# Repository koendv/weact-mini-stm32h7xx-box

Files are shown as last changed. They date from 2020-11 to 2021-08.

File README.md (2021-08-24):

# Box for WeAct MiniSTM32H7xx
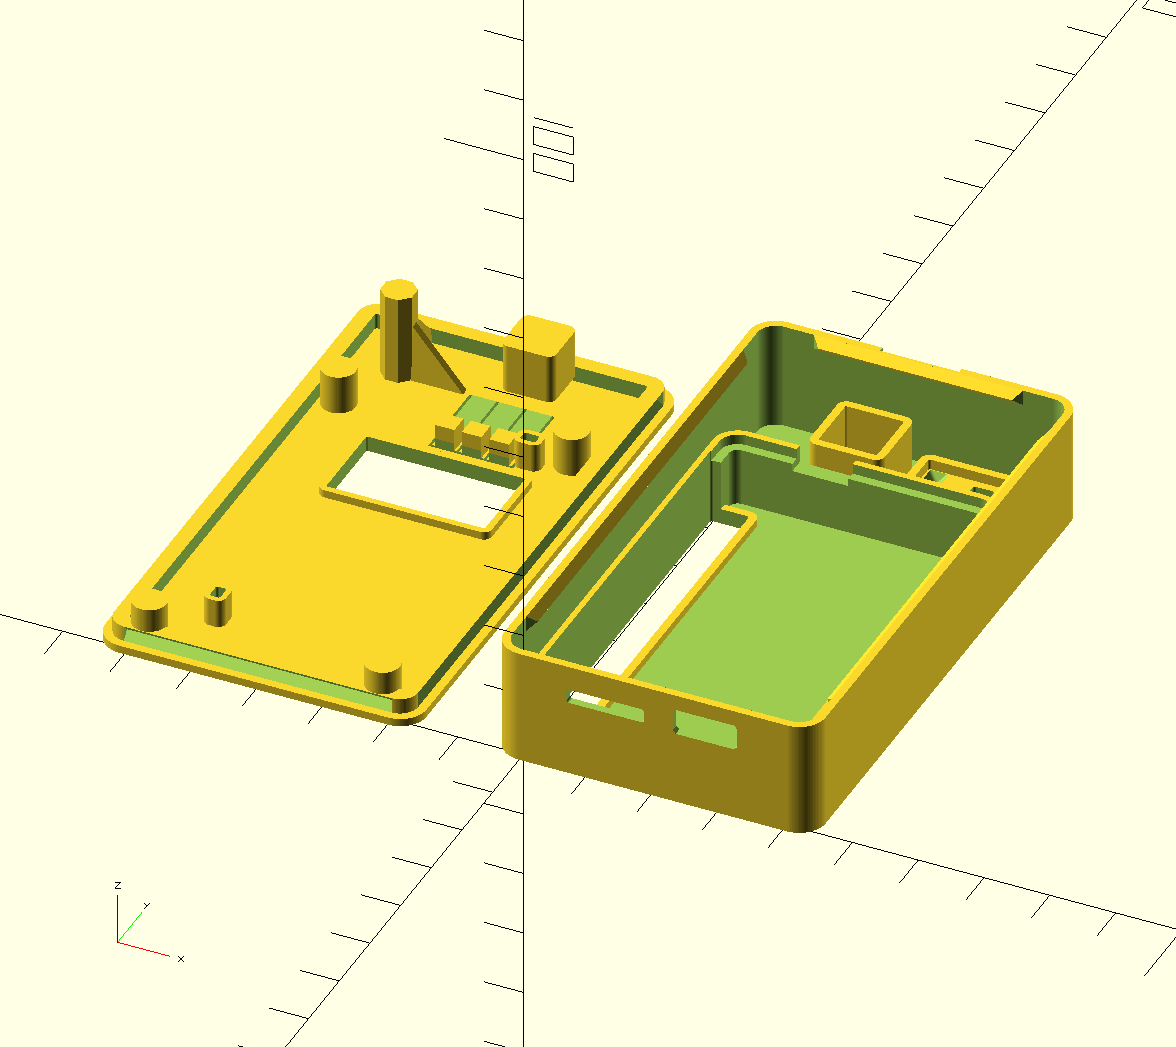
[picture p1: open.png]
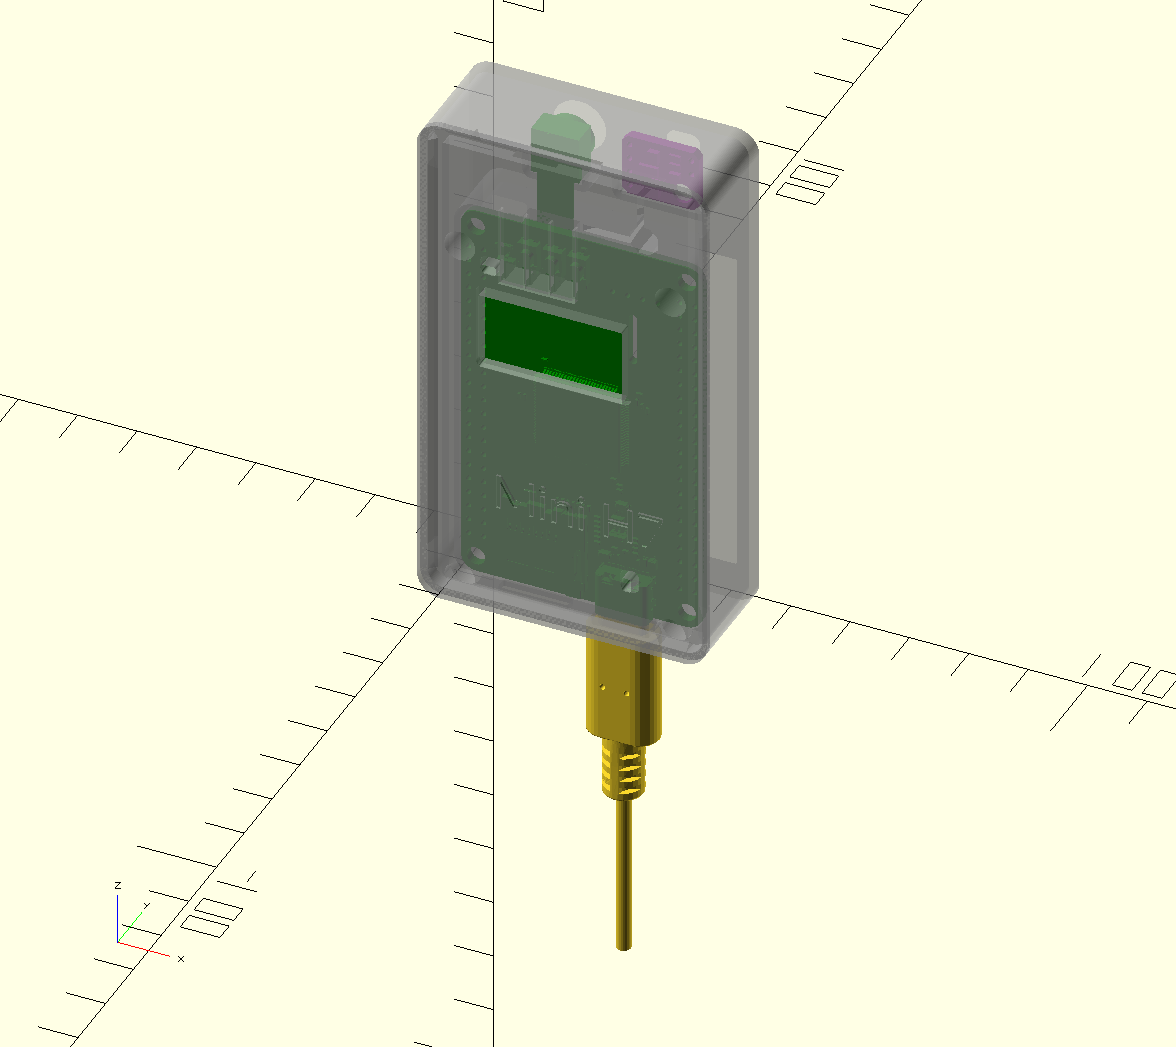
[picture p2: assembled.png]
|  |  |
|--|--|
| open | assembled|

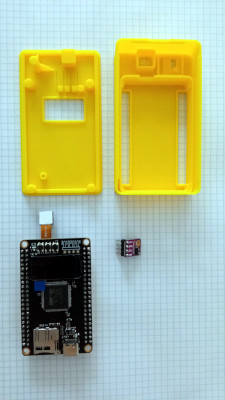
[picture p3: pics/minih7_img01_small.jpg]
before
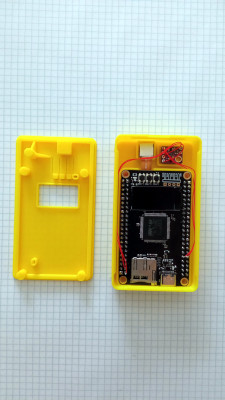
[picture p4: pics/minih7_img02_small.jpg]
after
| | |
|--|--|
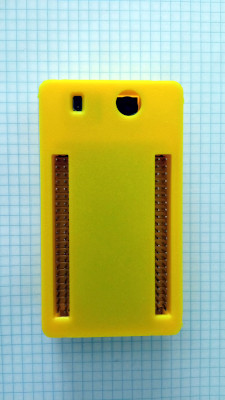
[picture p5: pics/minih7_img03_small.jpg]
back
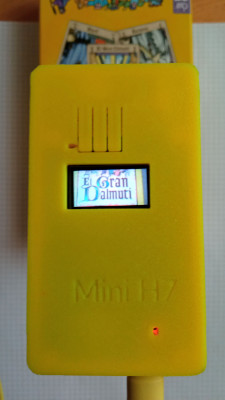
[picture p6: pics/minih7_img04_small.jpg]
front
| | |

This is a box for the [WeAct-TC MiniSTM32H7xx](https://github.com/WeActTC/MiniSTM32H7xx) board. The MiniSTM32H7xx runs micropython and openmv (Open Machine Vision). The board includes a camera and lcd screen.

Additionally, there is room to mount a [GY-530](GY-530.jpg) board, a VL53L0X time-of-flight laser range finder. This distance sensor can be used to check whether there is something in front of the lens. 

Connections for the optional VL53L0X laser range finder:

|VL53L0X|MiniSTM32H7xx|
|---|---|
|Vin|3V3|
|GND|GND|
|SCL|D12|
|SDA|D13|

## Download

[STL files](https://github.com/koendv/weact-mini-stm32h7xx-box/releases) for 3D printer. The box consists of two parts, a top and a bottom.

## Hardware

Notes about the WeAct-TC MiniSTM32H7xx camera hardware I'm using with OpenMV.

- [camera](https://www.aliexpress.com/item/1005001475058305.html) with lcd screen. Runs micropython.
- Installation [manual](https://github.com/WeActTC/MiniSTM32H7xx)
- How to [install the lcd](https://m.bilibili.com/video/av286164536)
- camera [firmware](https://gitee.com/WeAct-TC/MiniSTM32H7xx/tree/master/SDK/openmv/Firmwares/)
- [tool](https://gitee.com/WeAct-TC/MiniSTM32H7xx/tree/master/Soft) to upload firmware to the camera
- [openmv ide](https://github.com/koendv/openmv-ide-raspberrypi) for raspberry pi
- [VL53L0X](https://github.com/ramithuh/OpenMV-VL53L0X) laser distance sensor to check whether there is something in front of the camera

## OpenSCAD notes

This 3D model was made as follows:

- Download [3D model of MiniSTM32H7xx](https://github.com/WeActTC/MiniSTM32H7xx) pcb from WeAct git.
- Convert 3D model to stl with FreeCAD
- Extract 3D models of buttons, leds, connectors, pcb to stl with FreeCAD
- Download [3D model of GY-530](https://www.thingiverse.com/thing:2558558) from Thingiverse
- Import 3D models in OpenSCAD
- Use 3D models of leds, buttons and connectors as guides for holes in enclosure

*not truncated*

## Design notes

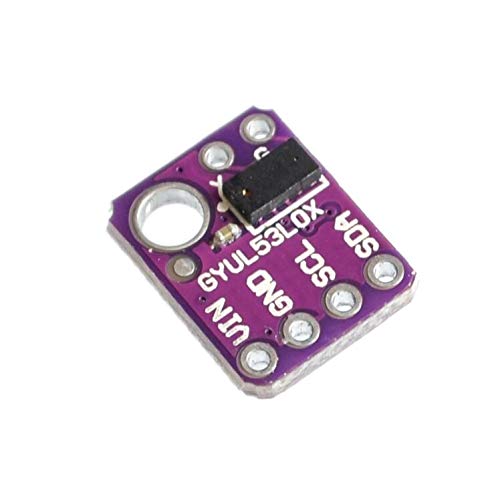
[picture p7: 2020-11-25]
GY-530.jpg

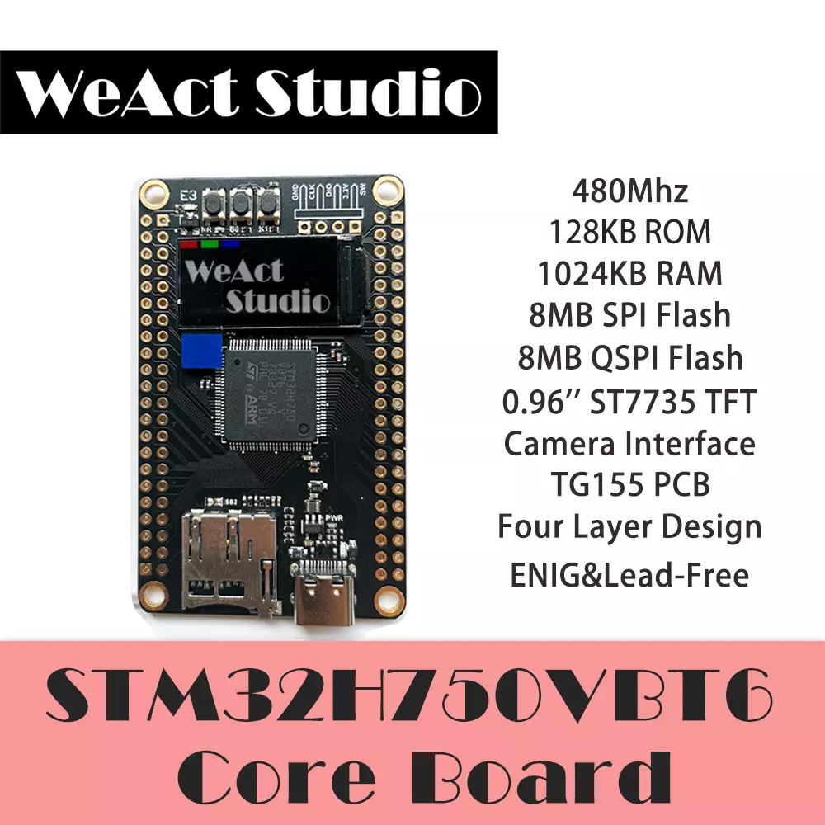
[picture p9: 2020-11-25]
MiniSTM32H7xx.jpg

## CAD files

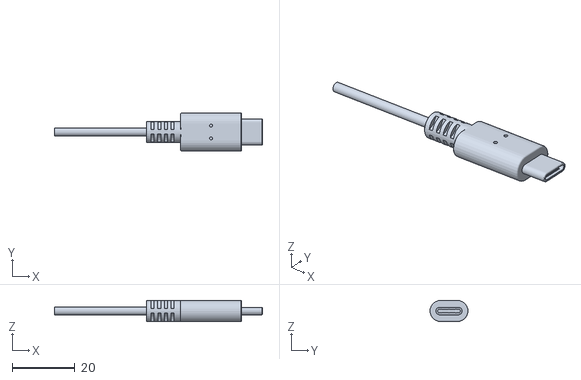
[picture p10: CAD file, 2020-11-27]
usb-c.stl
66.2 x 12.1 x 6.70

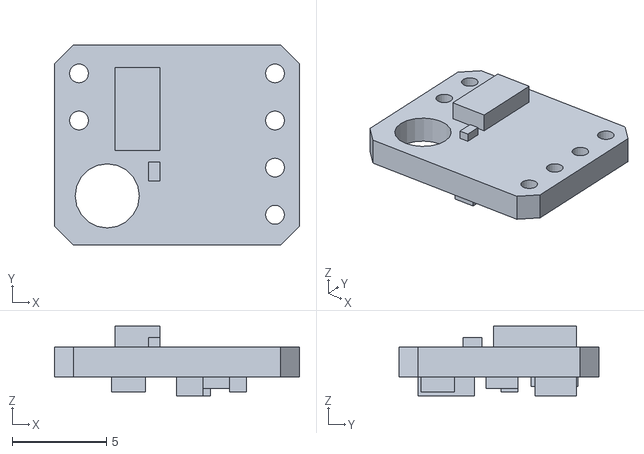
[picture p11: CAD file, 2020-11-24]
GY-530.stl
13.0 x 10.6 x 3.70

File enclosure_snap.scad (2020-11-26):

// Customizable snap-fit electronics project box enclosure
// https://www.thingiverse.com/thing:2866563/files


// Which one would you like to see?
part = "both"; // [box:Box only, top: Top cover only, both: Box and top cover]

// Size of your printer's nozzle in mm
nozzle_size = 0.4;

// Number of walls the print should have
number_of_walls = 3; // [1:5]

// Tolerance (use 0.2 for FDM)
tolerance = 0.2; // [0.1:0.1:0.4]

// Outer x dimension in mm
x=w1+2*number_of_walls*nozzle_size+nozzle_size;

// Outer y dimension in mm
y=h1+2*number_of_walls*nozzle_size+nozzle_size;

// Outer z dimension in mm
z=z1+2*number_of_walls*nozzle_size;

echo("Box:",x,y,z);

// Radius for rounded corners in mm
radius=4; // [1:20]

/* Hidden */
$fn=100;

wall_thickness=nozzle_size*number_of_walls;
hook_thickness = 3*nozzle_size;

top_cover_wall_thickness = hook_thickness + wall_thickness;

module bottom_box () {
    difference(){
        // Solid box
        linear_extrude(z-wall_thickness+eps1){
            minkowski(){
                square([x-radius*2,y-radius*2], center=true);
                circle(radius);
            }
        }
        
        // Hollow out
        translate([0,0,wall_thickness]) linear_extrude(z){
            minkowski(){
                square([x-radius*2-wall_thickness*2+wall_thickness*2,y-radius*2-wall_thickness*2+wall_thickness*2], center=true);
                circle(radius-wall_thickness);
            }
        }
    }
    left_hook(); // left hook
    rotate([180,180,0]) left_hook(); // right hook
    front_hook(); // front hook
    rotate([180,180,0]) front_hook(); // back hook
    // TODO: hooks on the other two sides
}

module left_hook () {
    
    translate([(x-2*wall_thickness)/2,-y/2+radius*2,z-wall_thickness]) rotate([0,90,90]) {
        difference(){
            linear_extrude(y-2*radius*2){
    polygon(points=[[0,0],[2*hook_thickness,0],[hook_thickness,hook_thickness]]);
        }
             translate([hook_thickness, hook_thickness, 0]) rotate([45,0,0]) cube(2*hook_thickness, center=true);
             translate([hook_thickness, hook_thickness, y-2*radius*2]) rotate([45,0,0]) cube(2*hook_thickness, center=true);        
        }
    }
}
    

module front_hook () {
    translate([(-x+4*radius)/2,-y/2+wall_thickness,z-wall_thickness]) rotate([90,90,90]) {
        difference(){
        linear_extrude(x-2*radius*2){
    polygon(points=[[0,0],[2*hook_thickness,0],[hook_thickness,hook_thickness]]);
    }
             translate([hook_thickness, hook_thickness, 0]) rotate([45,0,0]) cube(2*hook_thickness, center=true);
             translate([hook_thickness, hook_thickness, x-2*radius*2]) rotate([45,0,0]) cube(2*hook_thickness, center=true);
        }
    }
}


module right_groove () {
    translate([-tolerance/2+(x-2*wall_thickness)/2,-y/2+radius,wall_thickness+hook_thickness*2]) rotate([0,90,90]) linear_extrude(y-2*radius){
    polygon(points=[[0,0],[2*hook_thickness,0],[hook_thickness,hook_thickness]]);
    }
}


module front_groove () {
    translate([(-x+2*radius)/2,-y/2+wall_thickness+tolerance/2,wall_thickness+hook_thickness*2]) rotate([90,90,90]) linear_extrude(x-2*radius){
    polygon(points=[[0,0],[2*hook_thickness,0],[hook_thickness,hook_thickness]]);
    }
}

module top_cover () {

    // Top face
    linear_extrude(wall_thickness){
        minkowski(){
            square([x-radius*2,y-radius*2], center=true);
            circle(radius);
        }
    }
    
    difference(){
        // Wall of top cover
        linear_extrude(wall_thickness+hook_thickness*2){
            minkowski(){
                square([x-radius*2-wall_thickness*2-tolerance+wall_thickness*2,y-radius*2-wall_thickness*2-tolerance+wall_thickness*2], center=true);
                circle(radius-wall_thickness);
            }
        }
        
        // Hollow out
        // TODO: If radius is very small, still hollow out

        translate([0,0,wall_thickness]) linear_extrude(z){
            minkowski(){
                square([x-radius*2-wall_thickness*2-2*top_cover_wall_thickness-tolerance+wall_thickness*2+top_cover_wall_thickness*2,y-radius*2-wall_thickness*2-2*top_cover_wall_thickness-tolerance+wall_thickness*2+top_cover_wall_thickness*2], center=true);
            circle(radius-wall_thickness-top_cover_wall_thickness);
            }
        }
    right_groove();
    rotate([180,180,0]) right_groove();
    front_groove();
    rotate([180,180,0])  front_groove();
    }
  

}

// left_hook();
// print_part();

module print_part() {
	if (part == "box") {
		bottom_box();
	} else if (part == "top") {
		top_cover();
	} else if (part == "both") {
		both();
	} else {
		both();
	}
}

module both() {
	translate([0,-(y/2+wall_thickness),0]) bottom_box();
    translate([0,+(y/2+wall_thickness),0]) top_cover();
}

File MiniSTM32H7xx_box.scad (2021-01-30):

/*
 * Box for WeAct-TC Mini-STM32H7xx openmv board
 * and gy-530 vl53l0x laser ranging sensor.
 */

connector = true; // hole for dupont connectors
laser_distance_sensor = true; // hole for gy-530 vl53l0x laser ranging sensor

eps1=0.001;
eps2=2*eps1;
infinity=100;
inch=25.4;

top_z=6.0;    // top components
bottom_z=9.0; // bottom components
pcb_z=1.6;    // pcb

w1=46.0;
h1=85.0;
w2=40.64;
h2=66.88;
z1=top_z+pcb_z+bottom_z;
d1=5.2;
r1=d1/2; // distance screw center to pcb edge

/* camera */
cam_x=14.5;
cam_y=79.0;
cam_d=8.5;
cam_z_offset=1.2; // distance between camera flex cable and pcb

/* buttons */
button_y = 62.0;
button_x1 = 11.9;
button_x2 = 16.1;
button_x3 = 20.2;
button_w = 3.0;
button_h = 3.0;
button_z = top_z-1.3;
button_l = 13.6;

led_z = top_z - 1.6;

distance_sensor_x = 32.0;
distance_sensor_y = 79.0;
distance_sensor_z = 1.2-eps1;

usb_x = 28.22;
usb_y = 4.8;

clearance_fit=0.4;

include <enclosure_snap.scad>

/* through hole */
module hole(){
    translate([0,0,-infinity/2])
    linear_extrude(infinity)
    offset(nozzle_size/2)
    projection()
    children();
}

/* pcb screw centers */
module screw_positions() {
    translate([r1, r1, 0])
    children();
    translate([r1, h2-r1, 0])
    children();
    translate([w2-r1, h2-r1, 0])
    children();
    translate([w2-r1, r1, 0])
    children();
}

/* engraving */
module small_text(txt) {
    text_h=nozzle_size; // one layer
    translate([0,0,-text_h+eps1])
    linear_extrude(2*text_h) text(txt, size = 6, halign = "center", valign = "center",font="Lato:style=Regular");
}

// --------------------------------------------------------------------------------
// Imports from cad

module led1_hole() {
    translate([0,0,-infinity/2])
    linear_extrude(infinity)
    translate([31.2, 10.3])
    offset(nozzle_size)
    square([0.8,1.6], center=true);
}

module led2_hole() {
    translate([0,0,-infinity/2])
    linear_extrude(infinity)
    translate([8.0, 62.1])
    offset(nozzle_size)
    translate([-0.8,-0.4,0])
    square([1.6,0.8]); // gives thin wall
}

module led1_body() {
    translate([0,0,-wall_thickness-led_z])
    linear_extrude(led_z)
    offset(3*nozzle_size)
    translate([31.2, 10.3])
    square([0.8,1.6], center=true);
}

module led2_body() {
    translate([0,0,-wall_thickness-led_z])
    linear_extrude(led_z)
    offset(3*nozzle_size)
    translate([8.0, 62.1])
    square([1.6,0.8], center=true);
}

module distance_sensor() {
    // 3d model of gy-530 module, center of vl53l0x at [0,0,0]
    translate([-3.2,64.6,-3.7])
    import("GY-530.stl");
}

module distance_sensor_hole() {
    translate([distance_sensor_x,distance_sensor_y,distance_sensor_z])
    rotate([0,0,180])
    {
        // vl53l0x sensor
        translate([0,0,-wall_thickness/2])
        linear_extrude(wall_thickness*2)
        offset(nozzle_size)
        square([2.4,4.4],center=true);

        // cone cutout
        translate([0,0,-wall_thickness])
        hull() {
            translate([0,0,wall_thickness])
            linear_extrude(eps1)
            offset(nozzle_size)
            square([2.4,4.4],center=true);
            translate([0,0,-eps2])
            linear_extrude(eps2)
            offset(nozzle_size+wall_thickness)
            square([2.4,4.4],center=true);
            }

        // small cap
        translate([0.9,3.3,0.2])
        linear_extrude(0.9+eps1)
        offset(nozzle_size)
        square([0.6,1.0],center=true);

        // pins
        translate([7.3,1.8,1.1+eps1])
        hull() {
            linear_extrude(eps1)
            offset(nozzle_size)
            square([2.0,0.4*inch],center=true);
            translate([0,0,-1.2])
            linear_extrude(eps1)
            offset(nozzle_size)
            square([eps1,0.35*inch],center=true);
        }
    }
}

module distance_sensor_body() {
    translate([distance_sensor_x,distance_sensor_y,distance_sensor_z])
    rotate([0,0,180])
    {
        translate([-1.6,4.6,1.1])
        rotate([0,0,180/8])
        cylinder(d=3.2, h=1.2, $fn=8);

        translate([2.1,1.9,1.1]) {
            translate([0,0,-1.1])
            linear_extrude(1.1+eps1)
            offset(wall_thickness + nozzle_size)
            square([13.0,10.6], center = true);
            linear_extrude(1.6+eps1)
            difference() {
                offset(wall_thickness + nozzle_size)
                square([13.0,10.6], center = true);
                offset(nozzle_size)
                square([13.0,10.6], center = true);
            }
        }
    }
}

module distance_sensor_support() {
    support_h=wall_thickness+top_z+pcb_z+bottom_z+pcb_z+wall_thickness-distance_sensor_z-4.3;
    translate([distance_sensor_x,distance_sensor_y,0])
    rotate([0,0,180])
    translate([-1.6,4.6,0])
    mirror([0,0,1]) {
        rotate([0,0,180/8])
        cylinder(d=5.2,h=support_h,$fn=8);
        buttress_h=support_h*3/4;
        hull() {
            translate([0,-wall_thickness/2,buttress_h])
            cube([wall_thickness,wall_thickness,eps1]);
            cube([buttress_h,wall_thickness,eps1]);
        }
        rotate([0,0,-90])
        hull() {
            translate([0,-wall_thickness/2,buttress_h])
            cube([wall_thickness,wall_thickness,eps1]);
            cube([buttress_h,wall_thickness,eps1]);
        }
    }
}

module lcd_hole() {
    hole()
    translate([6.5,44,0])
    cube([23.7,12.8,eps1]);
}

module lcd_body() {
    translate([6.5,44,0])
    mirror([0,0,1])
    linear_extrude(2*wall_thickness)
    offset(wall_thickness)
    square([23.7,12.8]);
}

module button_body() {
    translate([0,0,-button_z/2]) {
        translate([button_x3, button_y,0])
        cube([button_w, button_h, button_z], center=true);

        translate([button_x2, button_y,0])
        cube([button_w, button_h, button_z], center=true);

        translate([button_x1, button_y,0])
        cube([button_w, button_h, button_z], center=true);
    }
}

module button_holes() {
    d = (button_x2 - button_x1)/2;
    x1 = button_x1 - d; // first
    x2 = button_x1 + d;
    x3 = button_x2 + d;
    x4 = button_x3 + d; // last
    y0 = button_y-button_h/2+button_l/2-clearance_fit;
    z0 = 4*wall_thickness+eps1;

    translate([x1, y0, 0])
    cube([clearance_fit, button_l, z0], center=true);

    translate([x2, y0, 0])
    cube([clearance_fit, button_l, z0], center=true);

    translate([x3, y0, 0])
    cube([clearance_fit, button_l, z0], center=true);

    translate([x4, y0, 0])
    cube([clearance_fit, button_l, z0], center=true);

    translate([(x1+x4)/2, button_y-button_h/2-clearance_fit/2, 0])
    cube([x4-x1+clearance_fit, clearance_fit, z0], center=true);

    translate([x1-clearance_fit/2, button_y+button_h/2, -2*wall_thickness])
    cube([x4-x1+clearance_fit, button_l-button_h-clearance_fit, wall_thickness]);
}

module usb() {

    usb_c_x2 = 9.0;
    usb_c_y2 = 3.2;
    usb_c_z2 = 9.5;
    
    if (1)
    translate([usb_x,0,0])
    rotate([90,0,0]) {    
        // plug
        translate([0,0,-usb_c_z2/2])
        linear_extrude(usb_c_z2)
        offset(delta=2*clearance_fit,chamfer=true)
        offset(-clearance_fit)
        mirror([0,1])
        translate([-usb_c_x2/2,-usb_c_y2])
        square([usb_c_x2,usb_c_y2]);
    }

}

module microsd() {
    // microsd card standard dimensions: 11x15x1mm
    h=15;
    translate([7.6,0,0])
    rotate([90,0,0])
    translate([0,clearance_fit,-h/2])
    linear_extrude(h)
    offset(clearance_fit)
    square([11,1.4]); // add 0.4 mm for bridging droop
}

module pcb_3d() {
    translate([0,0,pcb_z])
    import("MiniSTM32H7xx.stl");
    camera();
}

module camera() {
    translate([cam_x,cam_y,-cam_z_offset])
    rotate([0,180,0]) {
        translate([-4,-4,0])
        cube([8.0,8.0,4.6]);
        cylinder(d=8.0,h=6.0);
        translate([-3.0,-20.0,0])
        cube([6.0,20.0,0.35]);
    }
}

// hole for DuPont connectors
module connector_hole() {
    conn_h = wall_thickness+bottom_z+eps2;
    translate([0,0,-conn_h])
    linear_extrude(3*conn_h)
    offset(nozzle_size) {
        translate([r1,h2/2,0])
        square([0.2*inch,2.2*inch],center=true);
        translate([w2-r1,h2/2,0])
        square([0.2*inch,2.2*inch],center=true);
    };
}

module connector_body() {
    linear_extrude(2*wall_thickness)
    intersection() {
        offset(wall_thickness+nozzle_size) {
            translate([r1,h2/2,wall_thickness/2])
            square([0.2*inch,2.2*inch],center=true);
            translate([w2-r1,h2/2,wall_thickness/2])
            square([0.2*inch,2.2*inch],center=true);
        };
        pcb();
    }
}

// --------------------------------------------------------------------------------
// box top cover

module top() {
    difference() {
        top_body();
        top_holes();
    }
}

module top_body() {
    translate([w2/2, h1/2, 0])
    rotate([0,180,0])
    top_cover();
    top_pcb_support();
    camera_support();
    distance_sensor_support();
    led1_body();
    led2_body();
    button_body();
    lcd_body();
}
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

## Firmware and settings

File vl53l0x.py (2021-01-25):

from micropython import const
import ustruct
import time
import utime
import pyb
from machine import I2C

_IO_TIMEOUT = 1000
_SYSRANGE_START = const(0x00)
_EXTSUP_HV = const(0x89)
_MSRC_CONFIG = const(0x60)
_FINAL_RATE_RTN_LIMIT = const(0x44)
_SYSTEM_SEQUENCE = const(0x01)
_SPAD_REF_START = const(0x4f)
_SPAD_ENABLES = const(0xb0)
_REF_EN_START_SELECT = const(0xb6)
_SPAD_NUM_REQUESTED = const(0x4e)
_INTERRUPT_GPIO = const(0x0a)
_INTERRUPT_CLEAR = const(0x0b)
_GPIO_MUX_ACTIVE_HIGH = const(0x84)
_RESULT_INTERRUPT_STATUS = const(0x13)
_RESULT_RANGE_STATUS = const(0x14)
_OSC_CALIBRATE = const(0xf8)
_MEASURE_PERIOD = const(0x04)


class TimeoutError(RuntimeError):
    pass


class VL53L0X:
    def __init__(self, i2c, address=0x29):
        self.i2c = i2c
        self.address = address
        self.init()
        self._started = False

    def _registers(self, register, values=None, struct='B'):
        if values is None:
            size = ustruct.calcsize(struct)
            data = self.i2c.readfrom_mem(self.address, register, size)
            values = ustruct.unpack(struct, data)
            return values
        data = ustruct.pack(struct, *values)
        self.i2c.writeto_mem(self.address, register, data)

    def _register(self, register, value=None, struct='B'):
        if value is None:
            return self._registers(register, struct=struct)[0]
        self._registers(register, (value,), struct=struct)

    def _flag(self, register=0x00, bit=0, value=None):
        data = self._register(register)
        mask = 1 << bit
        if value is None:
            return bool(data & mask)
        elif value:
            data |= mask
        else:
            data &= ~mask
        self._register(register, data)

    def _config(self, *config):
        for register, value in config:
            self._register(register, value)

    def init(self, power2v8=True):
        self._flag(_EXTSUP_HV, 0, power2v8)

        # I2C standard mode
        self._config(
            (0x88, 0x00),

            (0x80, 0x01),
            (0xff, 0x01),
            (0x00, 0x00),
        )
        self._stop_variable = self._register(0x91)
        self._config(
            (0x00, 0x01),
            (0xff, 0x00),
            (0x80, 0x00),
        )

        # disable signal_rate_msrc and signal_rate_pre_range limit checks
        self._flag(_MSRC_CONFIG, 1, True)
        self._flag(_MSRC_CONFIG, 4, True)

        # rate_limit = 0.25
        self._register(_FINAL_RATE_RTN_LIMIT, int(0.25 * (1 << 7)),
                       struct='>H')

        self._register(_SYSTEM_SEQUENCE, 0xff)

        spad_count, is_aperture = self._spad_info()
        spad_map = bytearray(self._registers(_SPAD_ENABLES, struct='6B'))

        # set reference spads
        self._config(
            (0xff, 0x01),
            (_SPAD_REF_START, 0x00),
            (_SPAD_NUM_REQUESTED, 0x2c),
            (0xff, 0x00),
            (_REF_EN_START_SELECT, 0xb4),
        )

        spads_enabled = 0
        for i in range(48):
            if i < 12 and is_aperture or spads_enabled >= spad_count:
                spad_map[i // 8] &= ~(1 << (i >> 2))
            elif spad_map[i // 8] & (1 << (i >> 2)):
                spads_enabled += 1

        self._registers(_SPAD_ENABLES, spad_map, struct='6B')

        self._config(
            (0xff, 0x01),
            (0x00, 0x00),

            (0xff, 0x00),
            (0x09, 0x00),
            (0x10, 0x00),
            (0x11, 0x00),

            (0x24, 0x01),
            (0x25, 0xFF),
            (0x75, 0x00),

            (0xFF, 0x01),
            (0x4E, 0x2C),
            (0x48, 0x00),
            (0x30, 0x20),

            (0xFF, 0x00),
            (0x30, 0x09),
            (0x54, 0x00),
            (0x31, 0x04),
            (0x32, 0x03),
            (0x40, 0x83),
            (0x46, 0x25),
            (0x60, 0x00),
            (0x27, 0x00),
            (0x50, 0x06),
            (0x51, 0x00),
            (0x52, 0x96),
            (0x56, 0x08),
            (0x57, 0x30),
            (0x61, 0x00),
            (0x62, 0x00),
            (0x64, 0x00),
            (0x65, 0x00),
            (0x66, 0xA0),

            (0xFF, 0x01),
            (0x22, 0x32),
            (0x47, 0x14),
            (0x49, 0xFF),
            (0x4A, 0x00),

            (0xFF, 0x00),
            (0x7A, 0x0A),
            (0x7B, 0x00),
            (0x78, 0x21),

            (0xFF, 0x01),
            (0x23, 0x34),
            (0x42, 0x00),
            (0x44, 0xFF),
            (0x45, 0x26),
            (0x46, 0x05),
            (0x40, 0x40),
            (0x0E, 0x06),
            (0x20, 0x1A),
            (0x43, 0x40),

            (0xFF, 0x00),
            (0x34, 0x03),
            (0x35, 0x44),

            (0xFF, 0x01),
            (0x31, 0x04),
            (0x4B, 0x09),
            (0x4C, 0x05),
            (0x4D, 0x04),

            (0xFF, 0x00),
            (0x44, 0x00),
            (0x45, 0x20),
            (0x47, 0x08),
            (0x48, 0x28),
            (0x67, 0x00),
            (0x70, 0x04),
            (0x71, 0x01),
            (0x72, 0xFE),
            (0x76, 0x00),
            (0x77, 0x00),

            (0xFF, 0x01),
            (0x0D, 0x01),

            (0xFF, 0x00),
            (0x80, 0x01),
            (0x01, 0xF8),

            (0xFF, 0x01),
            (0x8E, 0x01),
            (0x00, 0x01),
            (0xFF, 0x00),
            (0x80, 0x00),
        )

        self._register(_INTERRUPT_GPIO, 0x04)
        self._flag(_GPIO_MUX_ACTIVE_HIGH, 4, False)
        self._register(_INTERRUPT_CLEAR, 0x01)

        # XXX Need to implement this.
        #budget = self._timing_budget()
        #self._register(_SYSTEM_SEQUENCE, 0xe8)
        #self._timing_budget(budget)

        self._register(_SYSTEM_SEQUENCE, 0x01)
        self._calibrate(0x40)
        self._register(_SYSTEM_SEQUENCE, 0x02)
        self._calibrate(0x00)

        self._register(_SYSTEM_SEQUENCE, 0xe8)

    def _spad_info(self):
        self._config(
            (0x80, 0x01),
            (0xff, 0x01),
            (0x00, 0x00),

            (0xff, 0x06),
        )
        self._flag(0x83, 3, True)
        self._config(
            (0xff, 0x07),
            (0x81, 0x01),

            (0x80, 0x01),

            (0x94, 0x6b),
            (0x83, 0x00),
        )
        for timeout in range(_IO_TIMEOUT):
            if self._register(0x83):
                break
            utime.sleep_ms(1)
        else:
            raise TimeoutError()
        self._config(
            (0x83, 0x01),
        )
        value = self._register(0x92)
        self._config(
            (0x81, 0x00),
            (0xff, 0x06),
        )
        self._flag(0x83, 3, False)
        self._config(
            (0xff, 0x01),
            (0x00, 0x01),

            (0xff, 0x00),
            (0x80, 0x00),
        )
        count = value & 0x7f
        is_aperture = bool(value & 0b10000000)
        return count, is_aperture
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

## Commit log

2020-11-24 tof laser
    [GY-530.stl]
2020-11-27 usb cable
    [MiniSTM32H7xx_box.scad, usb-c.stl]
2021-01-29 slot pry open
    [MiniSTM32H7xx_box.scad]
2021-01-30 cable offset
    [MiniSTM32H7xx_box.scad]
2021-01-30 nail groove
    [MiniSTM32H7xx_box.scad]
